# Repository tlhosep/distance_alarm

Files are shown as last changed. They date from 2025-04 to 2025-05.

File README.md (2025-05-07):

# Distance alarm using pi pico
Measure distances using raspberry pi pico

This project aims to support you in building a simple measuring application.

You need these components:

* Raspberry pi pico or better
* A power source, eg. 12V battery
* HC-SR04-P sensor
* 12v led or equivalent
* 1 npn transistor
* 1 2k2 resistor
* 2 10k resitors
* step-down regulator to convert to 5V
* 1602 HD44780 display with I2C connector or board
* some soldering equipment
* for the housing a 3D printer

The prototype looked like this:

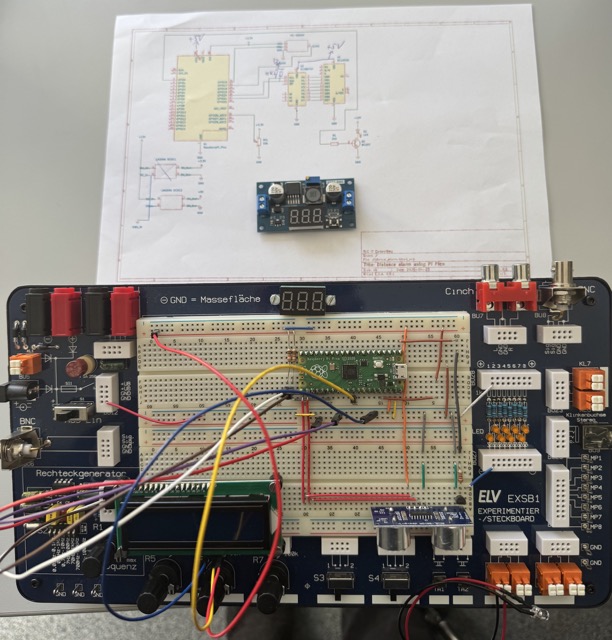
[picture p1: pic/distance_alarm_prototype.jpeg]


The alarm in operation looks like this:

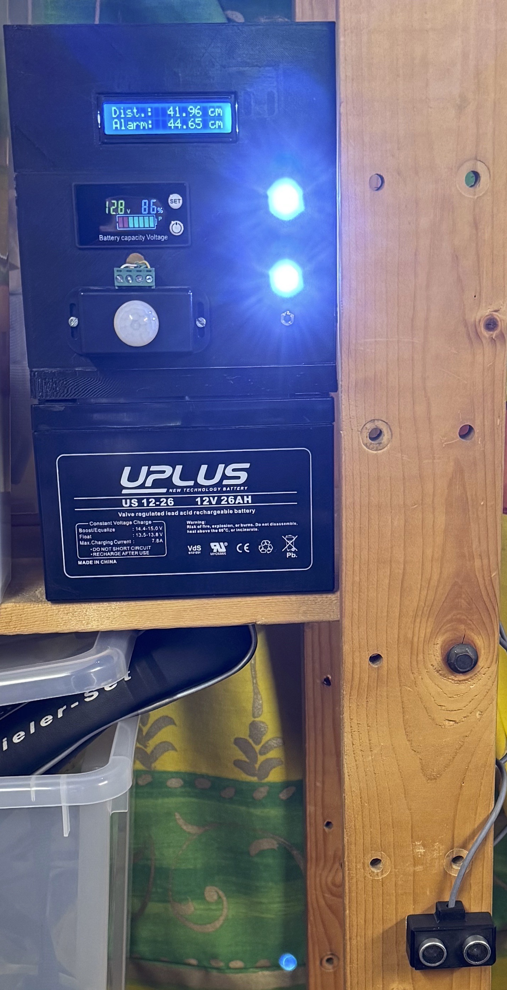
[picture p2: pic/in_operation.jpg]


The top LED is dimmed when distance gets greater, the lower LED indicates "in operation". The housings sit on a 12V battery, you could definetly use a one with lower capacity (!). Left to the LEDs you see a motion detector to turn on the power, so not always power is consumed. On top of that a display shows the capacity of the battery.

The distance sensor could be found on the lower end, fixed by tape on the IKEA shelf :) 

This is my layout, using mostly components that I had at hand:

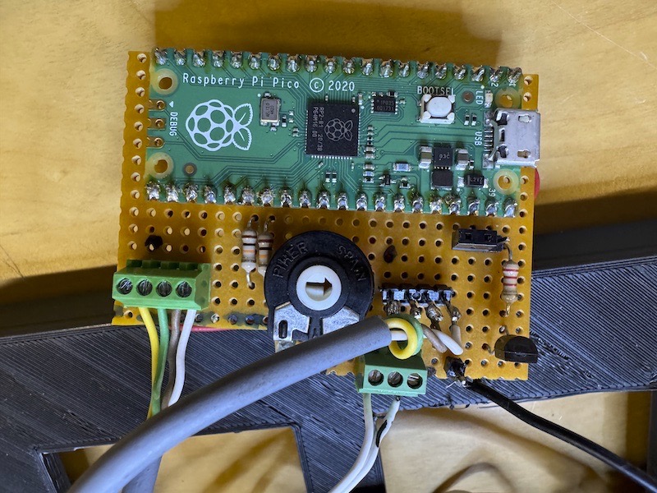
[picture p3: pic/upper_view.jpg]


Soldered end:

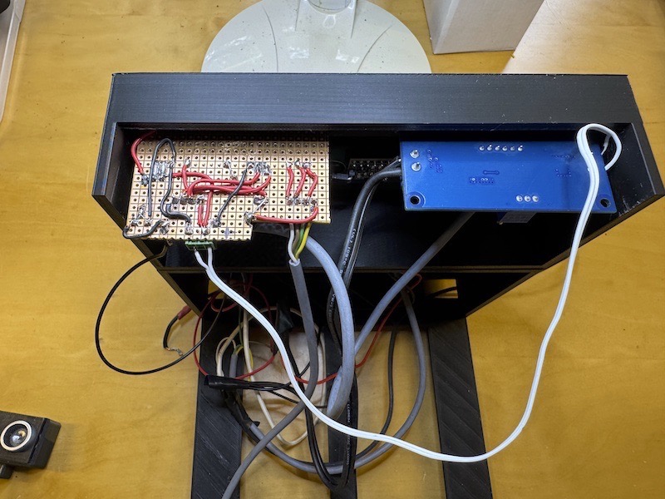
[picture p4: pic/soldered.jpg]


In my little laboratoy it looked like this showing the two possible information:

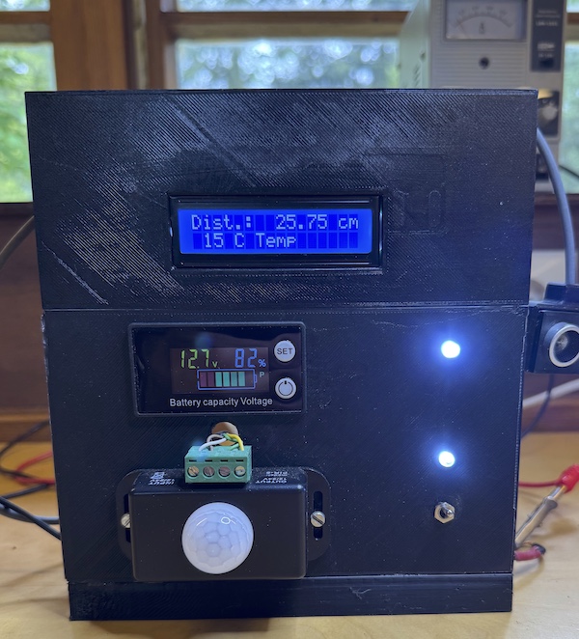
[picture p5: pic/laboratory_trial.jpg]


The temp is only shown occasionally...

But the setup distance/alarm (use the poti to set this up) shows in most cases:

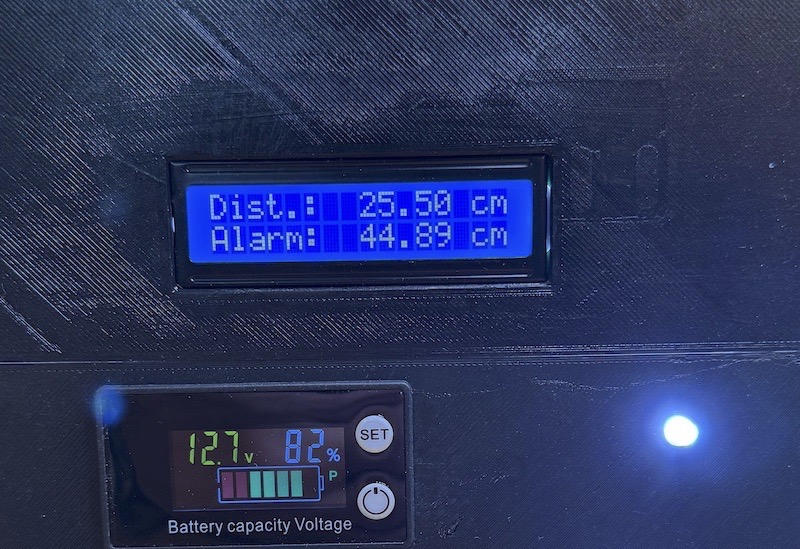
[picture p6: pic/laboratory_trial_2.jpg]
 

The schema and a pcb layout that may help you solder it (!not perfect, do not print!) could be found in the kicad folder.

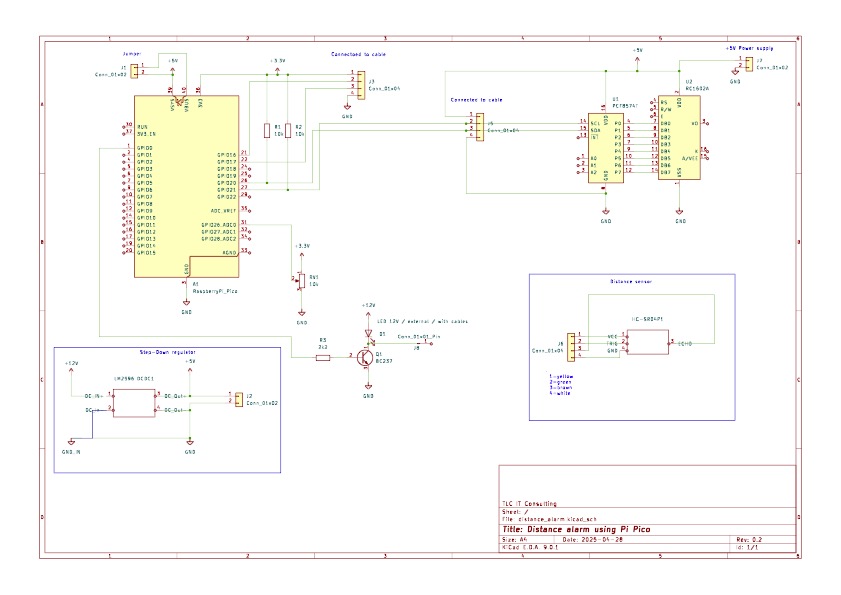
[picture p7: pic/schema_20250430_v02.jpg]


The stl and FCStd files are located in the freecad folder besides the box I used for the sensor and the original box for the display.

Please use thonny to test the application and your setup.

## Be careful
If you unsolder the pins from the HC-SR04-P sensor, make sure to solder a connection between the two layers. If you only connect to one layer some signals may get lost...

## About the housing
The housing for the lcd display should be rotated by 180° to show the info in the right direction. As I did not want to print the housing again, I simpoly rotated the whole housing...

The distance for the step-down pcb could be made a little bit wider...

## About the pcb
Th connector to the lcd is somehow wrong connected, not 1:1. Please be careful when you connect the display via I2C and use the right pins.

Do **not** use the pcp to print your board. Do only hard-wiring as I did or enhance the layout!

## About the LED
The 12v led is connected to the NPN Transistor. If you will use different LED-types, the transistor may not be needed.

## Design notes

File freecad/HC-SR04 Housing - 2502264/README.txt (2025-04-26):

HC-SR04 Housing by Waldi63 on Thingiverse: https://www.thingiverse.com/thing:2502264

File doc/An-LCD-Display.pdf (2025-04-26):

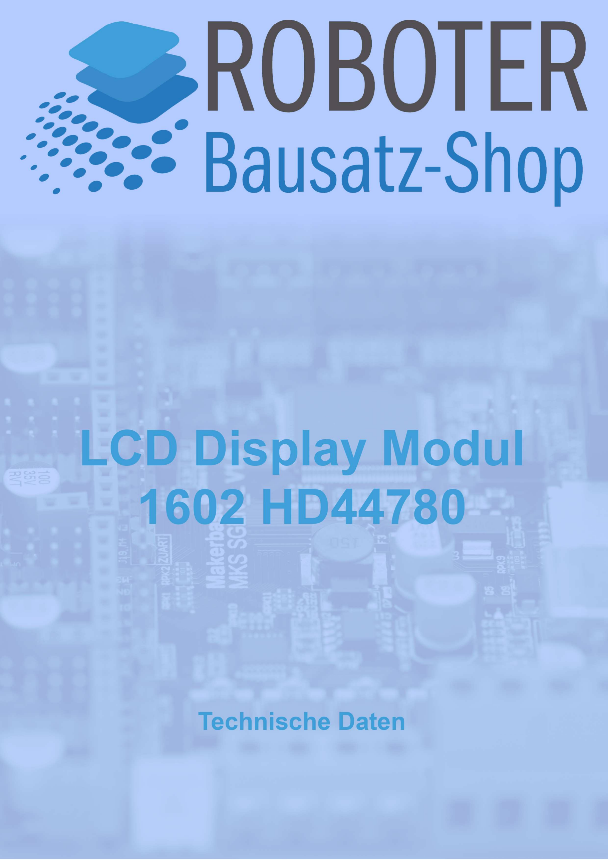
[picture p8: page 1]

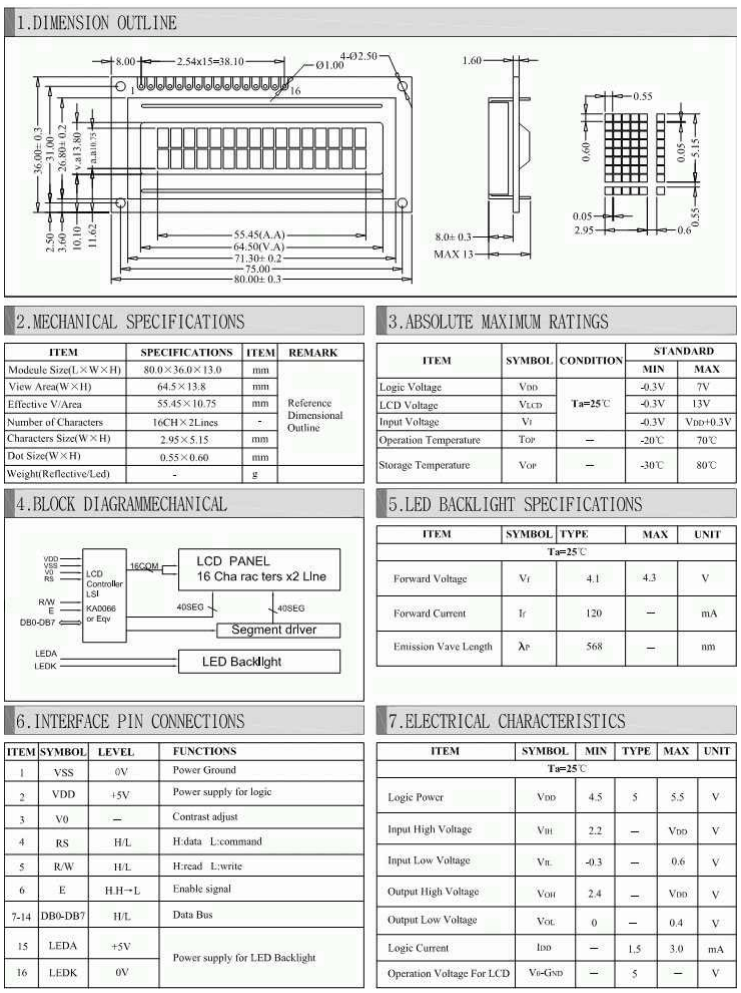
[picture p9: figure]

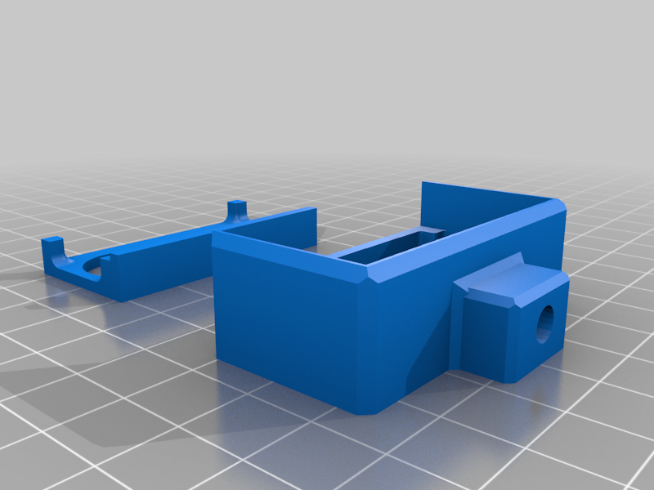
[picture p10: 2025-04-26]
freecad/HC-SR04 Housing - 2502264/images/286d23a098e2d05fe2ac7a46bd4b8489.png

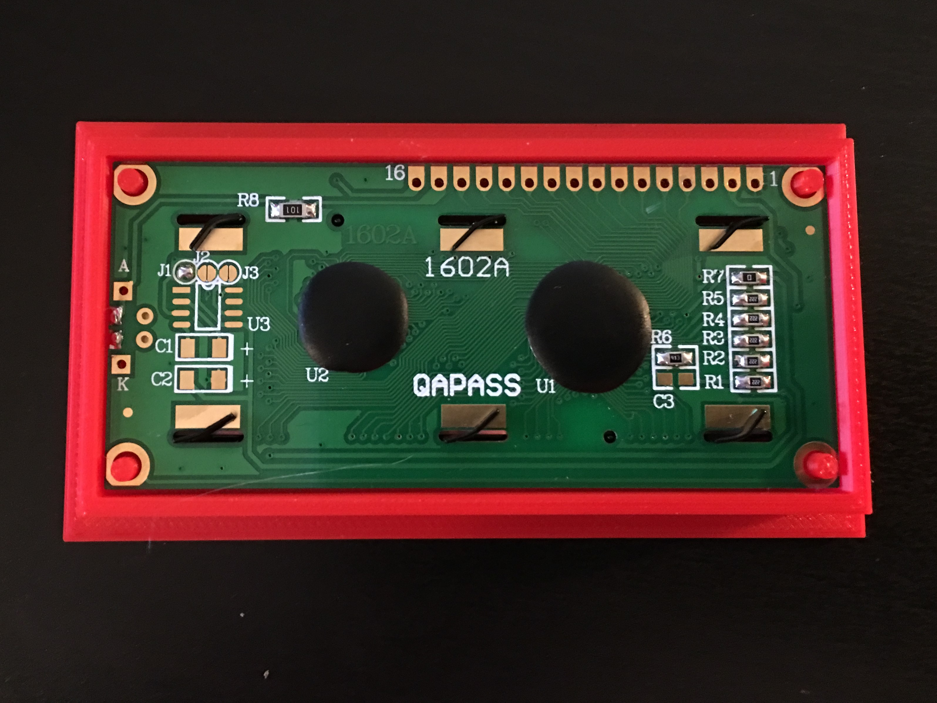
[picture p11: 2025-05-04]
freecad/1602 LCD Bezel - 3459425/images/20190228_172927137_iOS_2.jpg

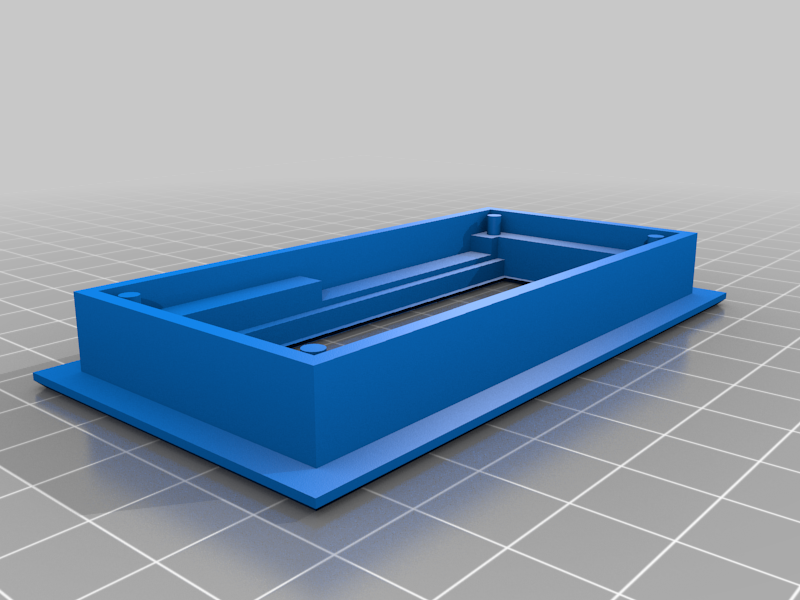
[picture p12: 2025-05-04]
freecad/1602 LCD Bezel - 3459425/images/2b1b6df83810f5e8bc768e8f024c8c7b.png

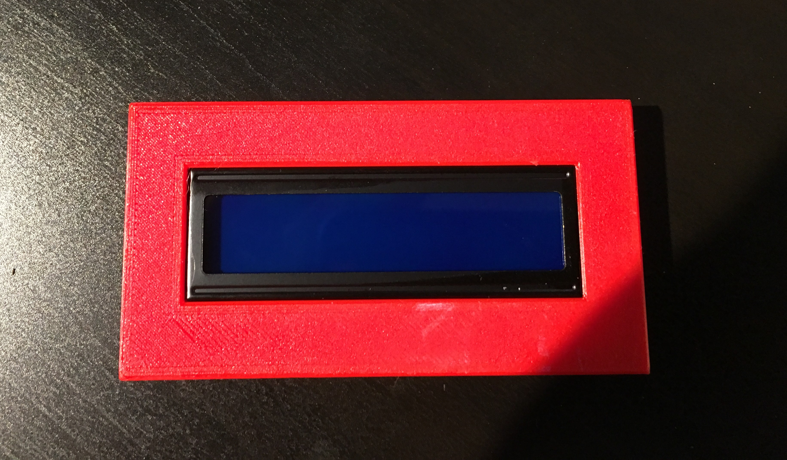
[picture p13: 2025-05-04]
freecad/1602 LCD Bezel - 3459425/images/20190228_172849651_iOS_2.jpg

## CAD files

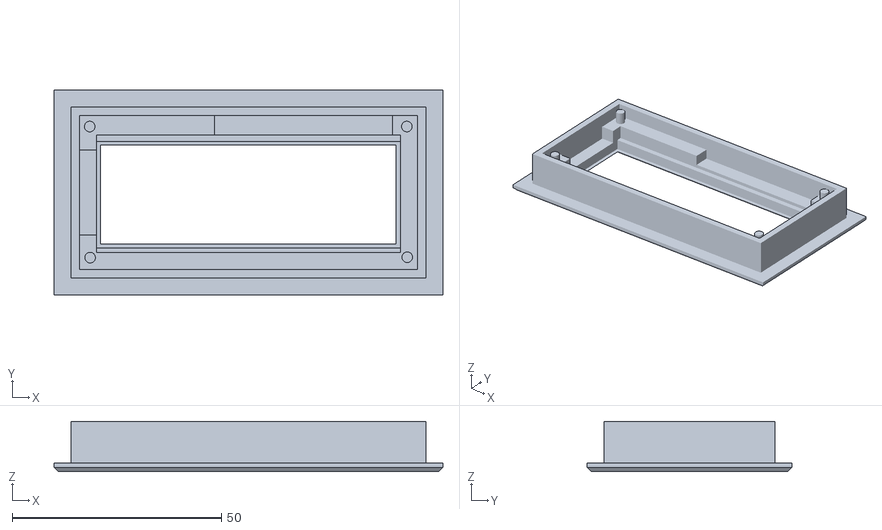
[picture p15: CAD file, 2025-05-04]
freecad/1602 LCD Bezel - 3459425/files/1602_LCD_Bezel.stl
93.0 x 49.0 x 12.0

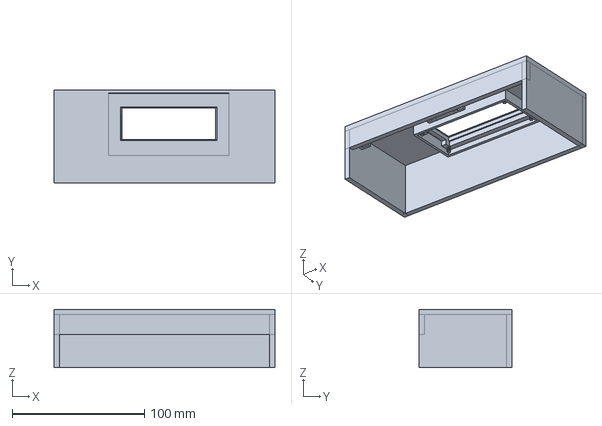
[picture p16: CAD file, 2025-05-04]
freecad/alarm_top_box.FCStd
167.0 x 70.0 x 44.1 mm

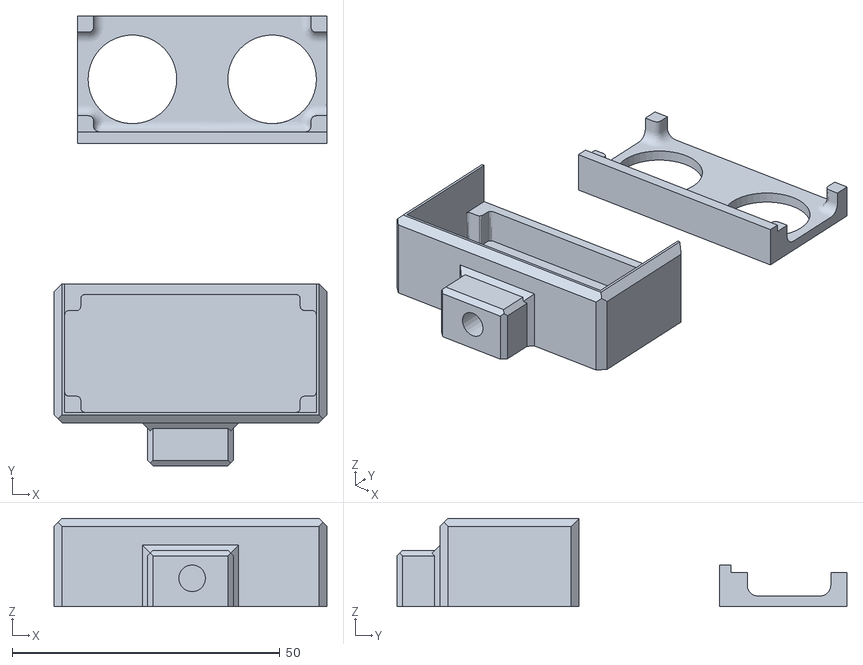
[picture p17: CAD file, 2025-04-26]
freecad/HC-SR04 Housing - 2502264/files/HC-SR04_box.stl
51.0 x 84.0 x 16.5

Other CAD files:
freecad/alarm_top_box-Fusion001.stl

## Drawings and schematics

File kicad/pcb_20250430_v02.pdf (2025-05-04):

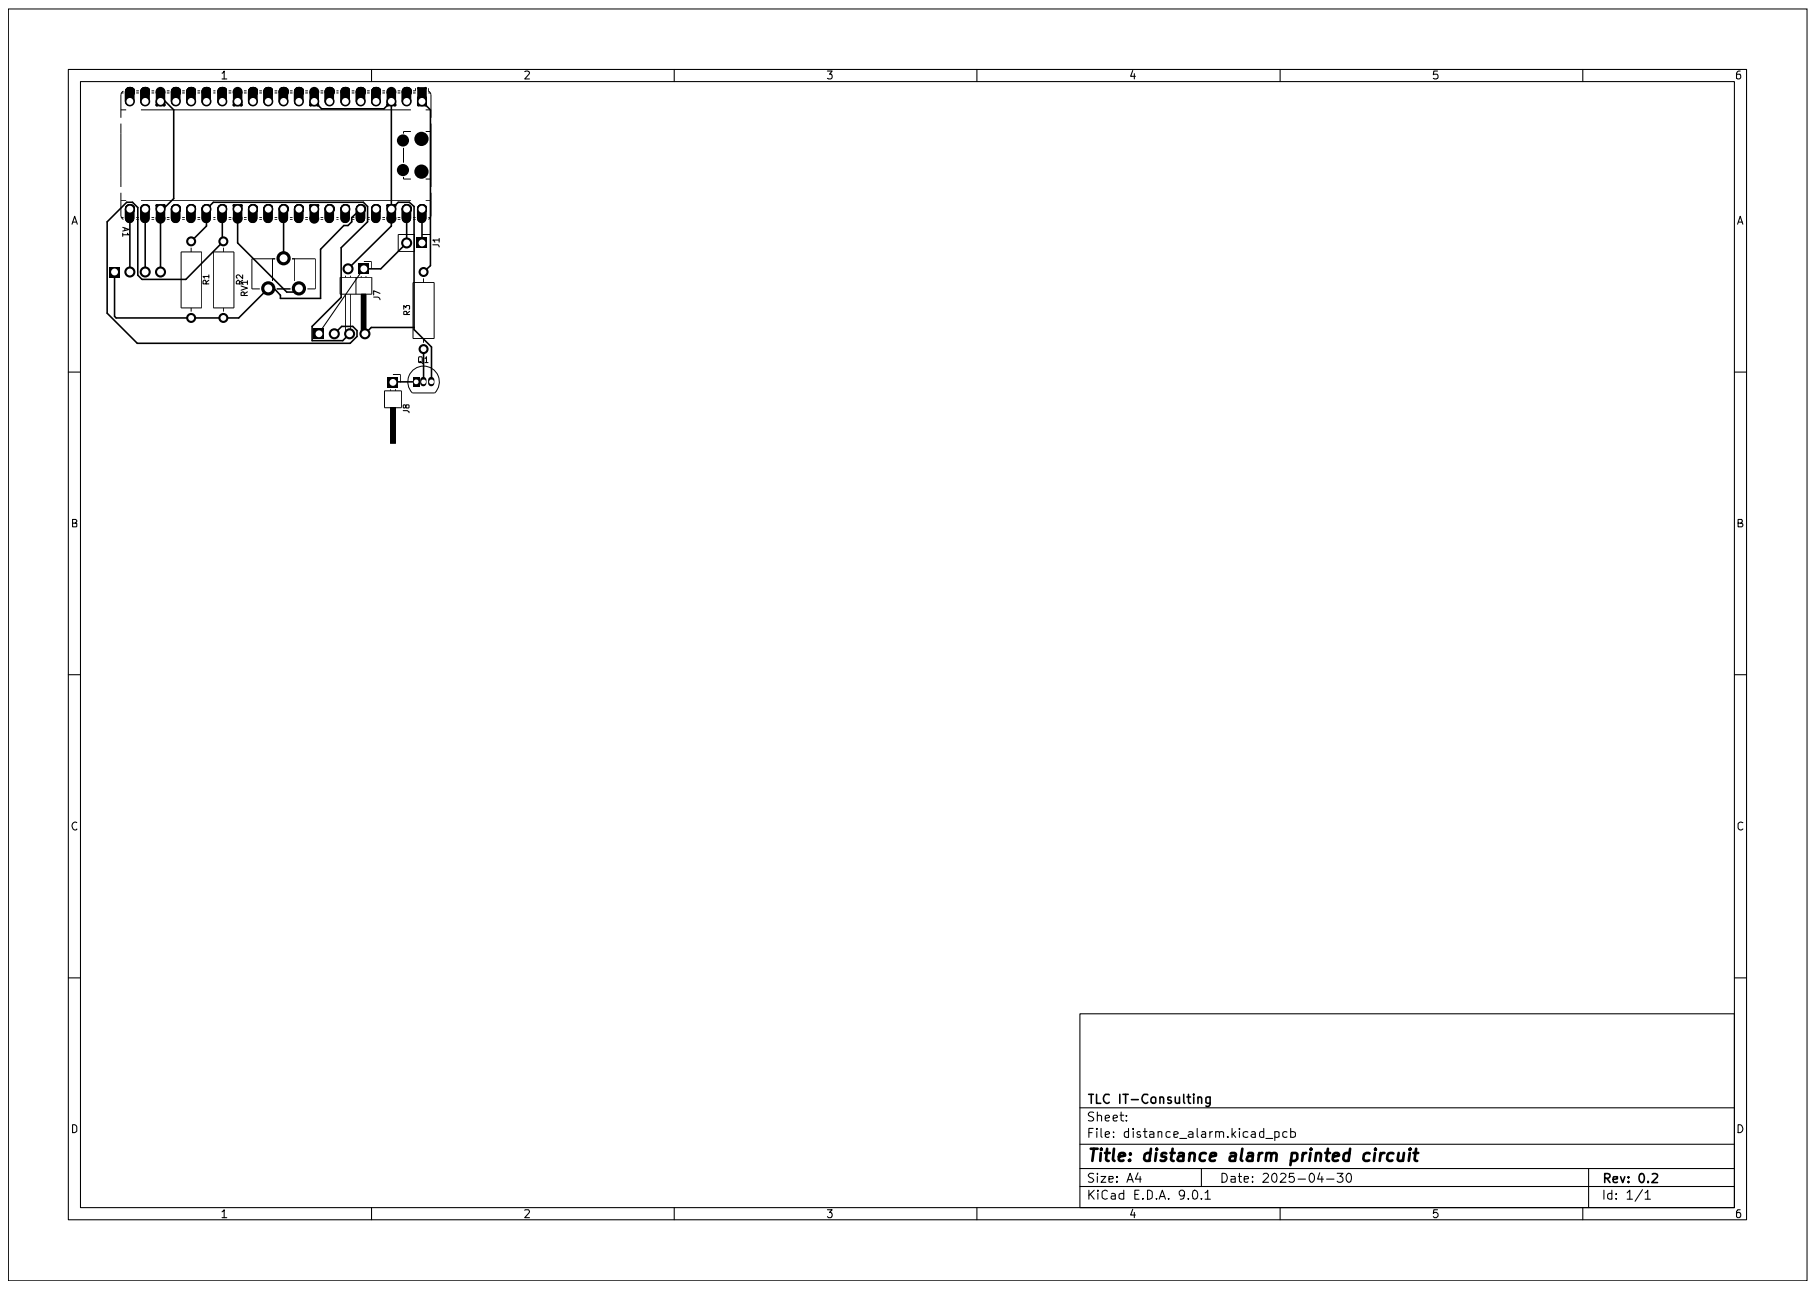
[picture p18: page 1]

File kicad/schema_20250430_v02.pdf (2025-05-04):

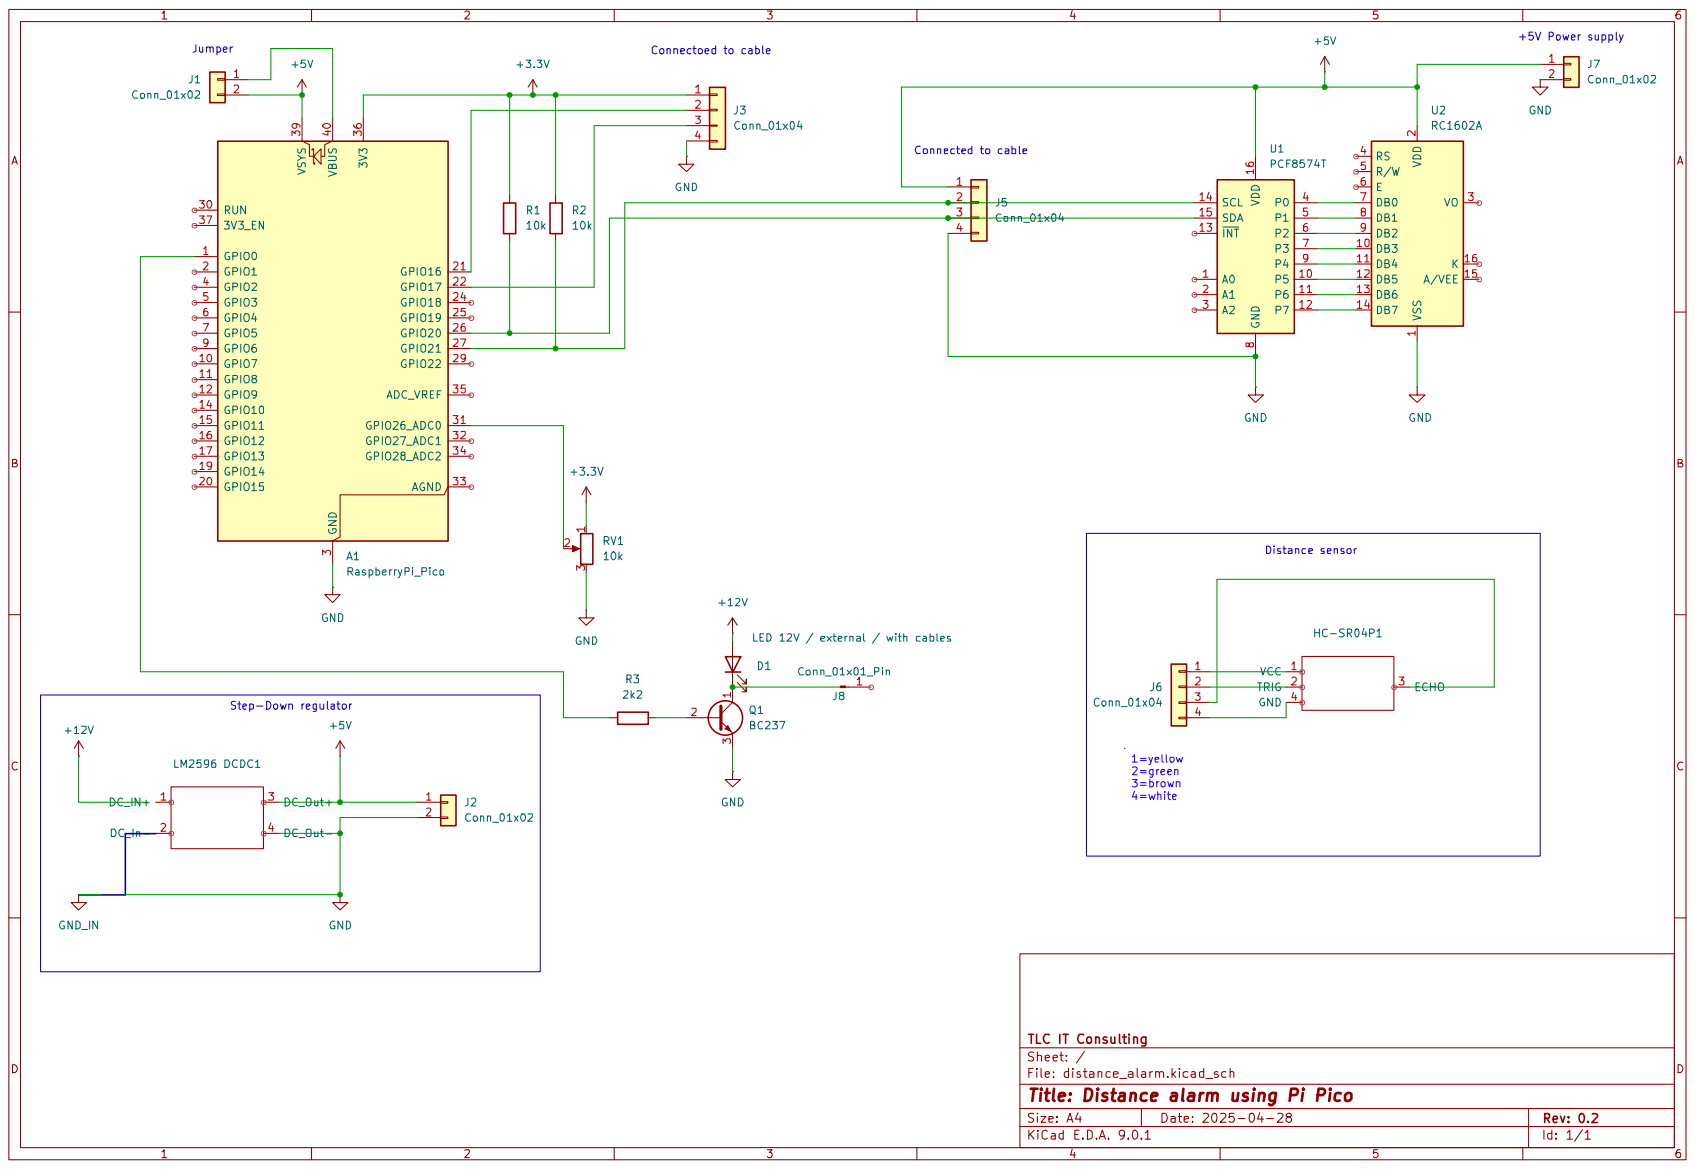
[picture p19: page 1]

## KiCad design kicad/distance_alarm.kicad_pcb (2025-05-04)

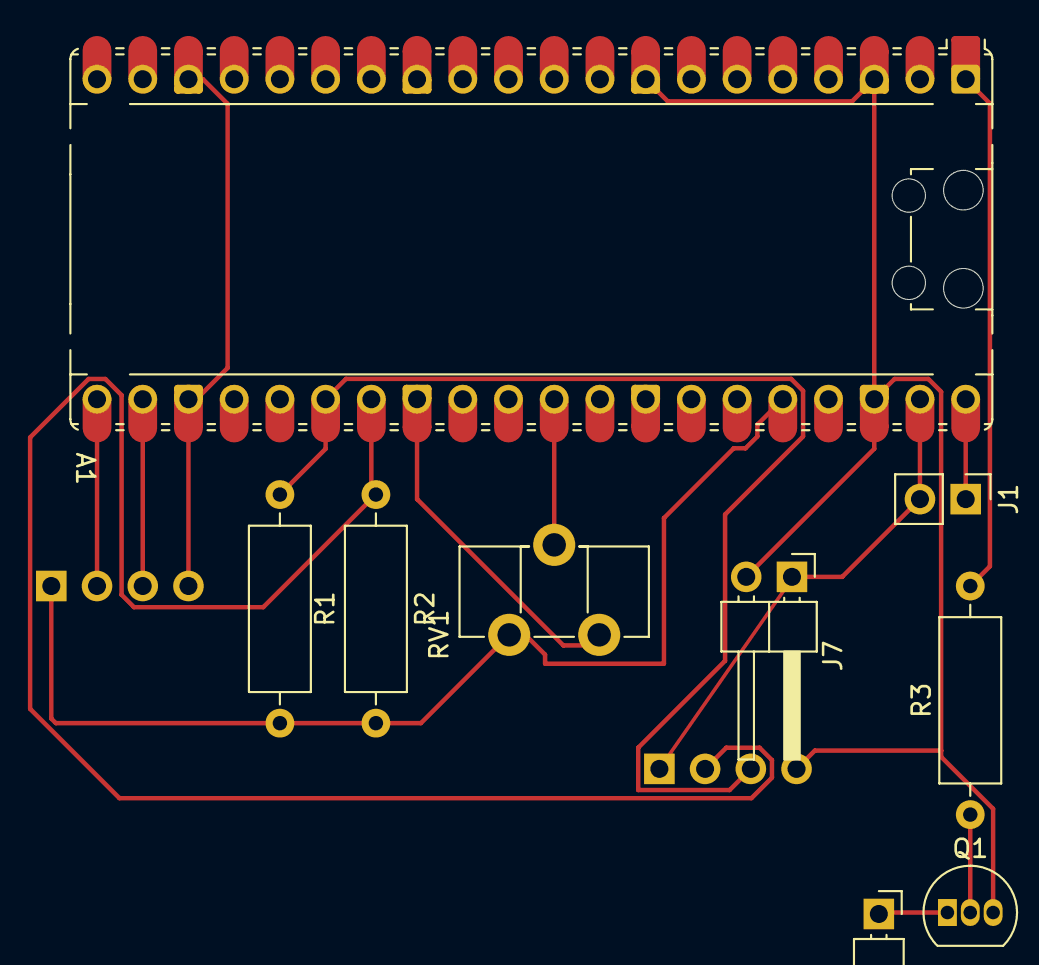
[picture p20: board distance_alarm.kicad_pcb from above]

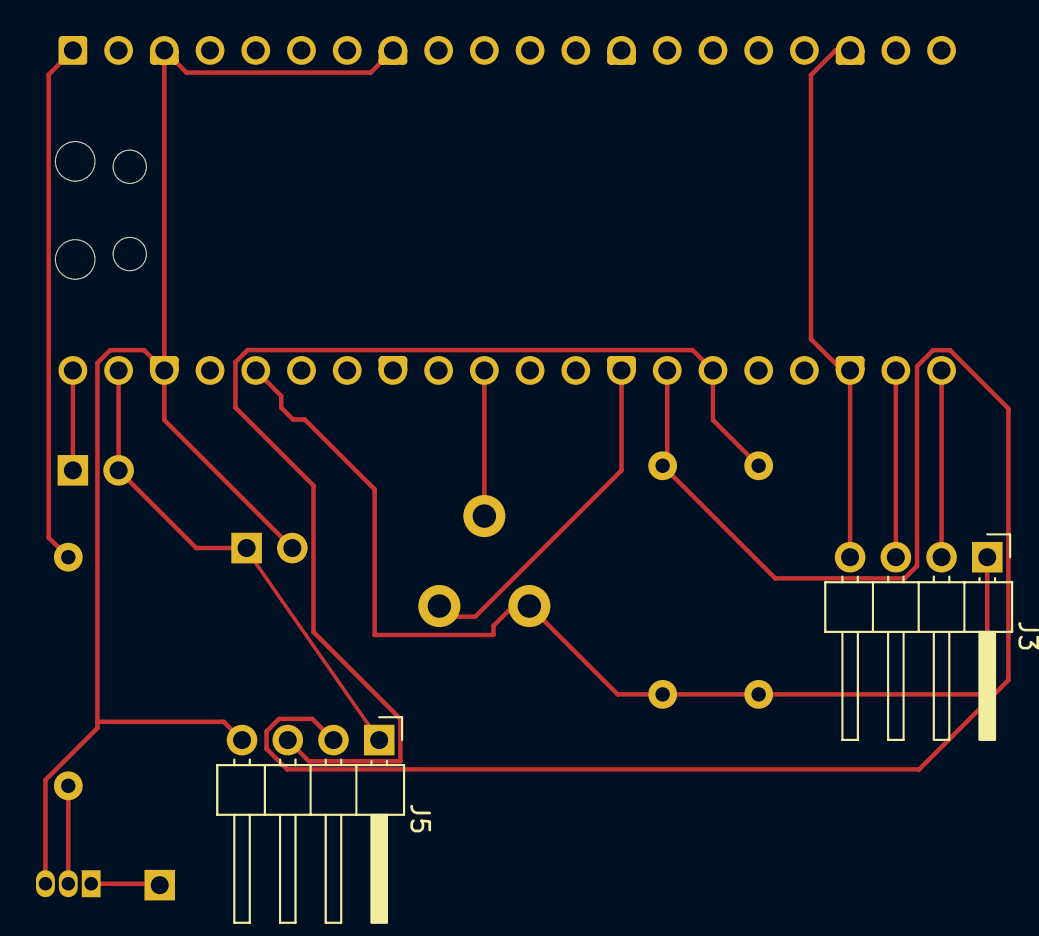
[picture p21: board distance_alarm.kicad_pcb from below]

Board: 2 copper layers, 11 parts (2 on the bottom side), 12 nets.

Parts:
A1: RaspberryPi_Pico; RaspberryPi_Pico_Common_Unspecified
J1: Conn_01x02; PinHeader_1x02_P2.54mm_Vertical
J3, J5: Conn_01x04; PinHeader_1x04_P2.54mm_Horizontal
J7: Conn_01x02; PinHeader_1x02_P2.54mm_Horizontal
J8: Conn_01x01_Pin; PinHeader_1x01_P2.54mm_Horizontal
Q1: BC237; TO-92_Inline
R1, R2: 10k; R_Axial_DIN0309_L9.0mm_D3.2mm_P12.70mm_Horizontal
R3: 2k2; R_Axial_DIN0309_L9.0mm_D3.2mm_P12.70mm_Horizontal
RV1: 10k; Potentiometer_Piher_PT-10-H05_Horizontal

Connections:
+3.3V: A1.36 (3V3), J3.1, R1.2, R2.2, RV1.1
+5V: A1.39 (VSYS), J1.2, J5.1, J7.1
GND: A1.3 (GND), A1.8 (GND), A1.13 (GND), A1.18 (GND), A1.23 (GND), A1.28 (GND), A1.38 (GND), J3.4, J5.4, J7.2, Q1.3 (E), RV1.3
unnamed: A1.1 (GPIO0), R3.2
unnamed: A1.21 (GPIO16), J3.2
unnamed: A1.22 (GPIO17), J3.3
unnamed: A1.26 (GPIO20), J5.3, R1.1
unnamed: A1.27 (GPIO21), J5.2, R2.1
unnamed: A1.31 (GPIO26_ADC0), RV1.2
unnamed: A1.40 (VBUS), J1.1
unnamed: J8.1, Q1.1 (C)
unnamed: Q1.2 (B), R3.1

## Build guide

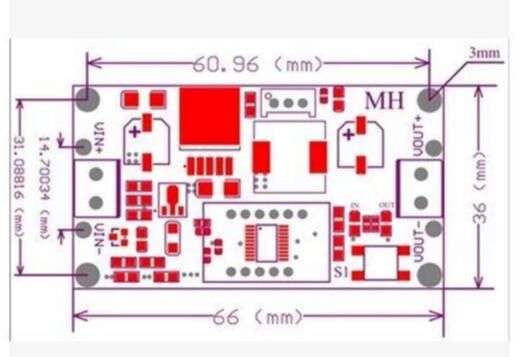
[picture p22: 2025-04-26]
doc/LM2596-Step-Down_Measures.jpg

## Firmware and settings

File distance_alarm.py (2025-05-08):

"""
PiPico Distance measuring with alarm and display
------------------------------------------------

This app uses

* Raspberry Pi Pico
* HC-SR04-P to measure the distance
* 1602 HD44780 2 line LCD display with I2C Bus
* 12V LED to show an alarm
* step down converter to 5.0 V
* 12 V Battery
* 10kOhm potentiometer
* 1Resistor 2k2
* 1Transistor NPN
* 2Resistors 10k

Info::

    Author.: (c) Thomas Lüth 2025
    Email..: info@tlc-it-consulting.com
    Created: 2025-04-23

Code
^^^^
"""
from time import sleep_ms
import utime
from machine import Pin, I2C, PWM, ADC
from machine_i2c_lcd import I2cLcd

VERSION = "1.2"
alarm_led = PWM(Pin(0))
alarm_led.freq(10000) #1000hz
alarm_led.duty_u16(32767>>6) #dark
trig = Pin(16, Pin.OUT)
echo = Pin(17, Pin.IN)
poti = ADC(0)
temp = ADC(4)
i2c = I2C(0, sda=Pin(20), scl=Pin(21), freq=100000)
lcd = I2cLcd(i2c, 0x27, 2, 16)
#start with version info
lcd.backlight_on()
trig.value(1)
lcd.putstr("Distance-alarm"+"\n"+"Version: "+VERSION)
sleep_ms(1000)
show_temp=0
TEMP_CONV = 3.3 / 65535
ALARM_CONV= 330 / 65535
no_measure=False

def calc_bar(alarm_dif:float, interval:float)->str:
    """Create the bar to show the distance left

    Args:
        alarm_dif (float): cm left until alarm level has been reached
        interval (float): increments for one char at the bar

    Returns:
        str: created bar-str up to 16char
    """
    steps=16-int(alarm_dif/interval)
#    print(f"steps:{steps:d} dif={alarm_dif:3.0f}")
    steps=min(16,steps)
    steps=max(1,steps)
    bar=""
    for _i in range(0,steps):
        bar += "\xff"
    return bar

while True:
    alarm_distance_raw=poti.read_u16()
    alarm_distance_cm=10.0+(alarm_distance_raw*ALARM_CONV)
    trig.value(0)
    utime.sleep_us(10)
    trig.value(1)
    utime.sleep_us(10)
    trig.value(0)
    fault_detection=1000
    while echo.value()==0 and fault_detection > 0:
        fault_detection-=1
    no_measure=fault_detection<1
    dist_diff_cm=200.0
    if not no_measure:
        tmr_start=utime.ticks_us()
        while echo.value()==1:
            pass
        tmr_end=utime.ticks_us()
        duration=utime.ticks_diff(tmr_end,tmr_start)
        distance_cm=duration*0.0171
        dist_diff_cm = distance_cm - alarm_distance_cm

    if dist_diff_cm < 5.0:
        alarm_led.freq(1000) #full on
        alarm_led.duty_u16(65535)
    elif dist_diff_cm < 15.0:
        alarm_led.freq(1000)
        alarm_led.duty_u16(32767)
    elif dist_diff_cm < 20.0:
        alarm_led.freq(1000)
        alarm_led.duty_u16(32767>>2)
    elif dist_diff_cm < 50.0:
        alarm_led.freq(1000)
        alarm_led.duty_u16(32767>>4)
    elif dist_diff_cm < 100.0:
        alarm_led.freq(1000)
        alarm_led.duty_u16(32767>>5)
    else:
        alarm_led.freq(1000)
        alarm_led.duty_u16(32767>>6)

    lcd.clear()
    if no_measure:
        msg1="Error:No measure"
    else:
        msg1=f"Distance: {distance_cm:3.0f} cm"
    if show_temp >3:
        volt = temp.read_u16() * TEMP_CONV
        room_temp=27-(volt-0.706)/0.001721
        msg2=f"Roomtemp = {room_temp:2.0f} C"
        show_temp=0
    elif show_temp == 2:
        msg2=f"Alarm = {alarm_distance_cm:3.0f} cm"
    else:
        msg2=calc_bar(dist_diff_cm,5.0)
    lcd.putstr(msg1+ "\n" +msg2)
    sleep_ms(1000)
    show_temp += 1

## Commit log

2025-04-26 Inital population with an early version
    [HC-SR04_box.stl, distance_alarm.kicad_pcb, distance_alarm.kicad_sch]
2025-05-04 Working application
    [1602_LCD_Bezel.stl, alarm_top_box-Fusion001.stl, alarm_top_box.FCStd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]
2025-05-07 Updated version, no longer blinking but dimmed
    [distance_alarm.py]
